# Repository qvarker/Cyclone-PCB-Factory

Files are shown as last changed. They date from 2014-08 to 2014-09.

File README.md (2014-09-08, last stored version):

Cyclone-PCB-Factory v0.9.7  
===================

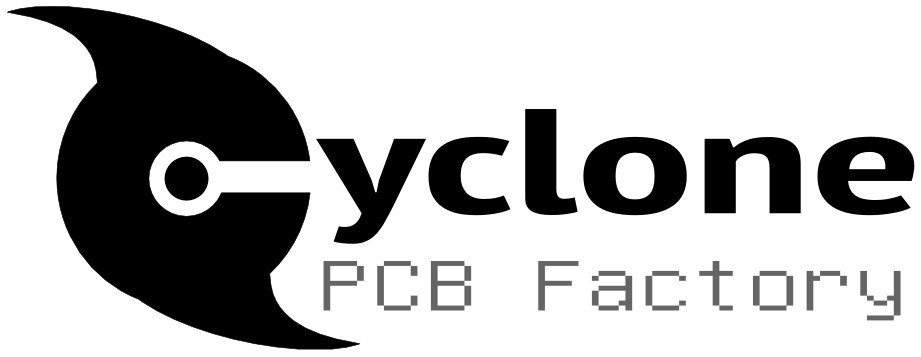
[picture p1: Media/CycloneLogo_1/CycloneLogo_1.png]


The first 3D-printable (Rep-Rap alike) CNC machine, intended for PCB manufacture.  

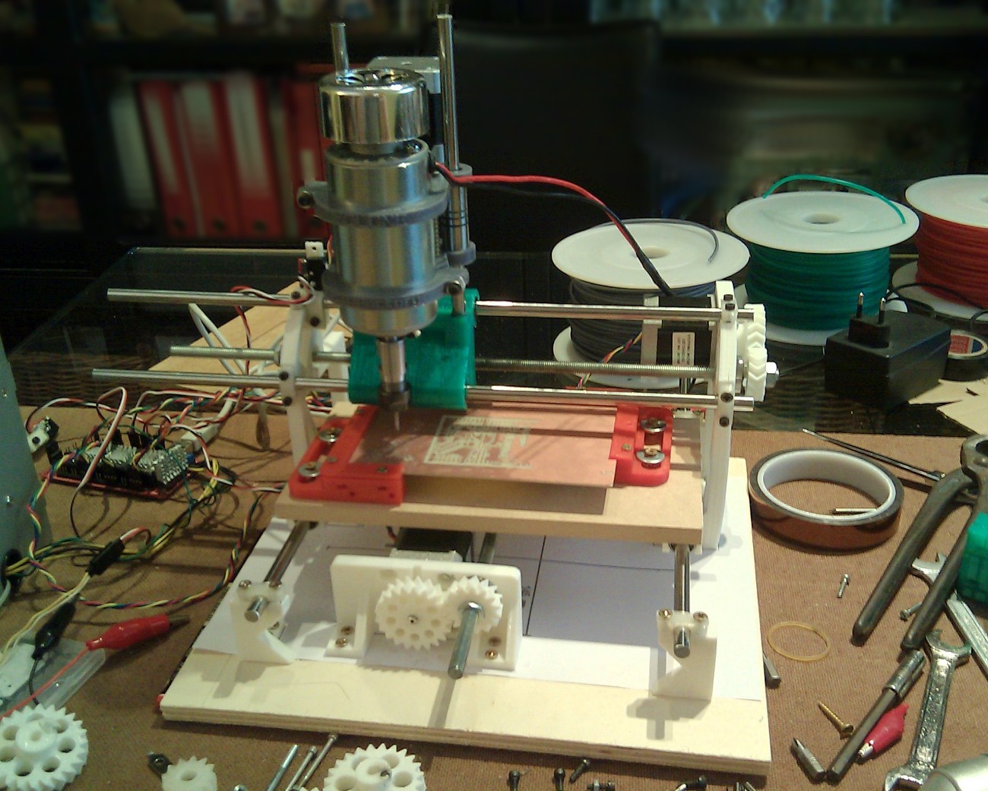
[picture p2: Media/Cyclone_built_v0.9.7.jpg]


Mail list / Forum  
--
If you are interested in this project, please consider joining our mail list:  
**<https://groups.google.com/forum/#!forum/cyclone-pcb-factory>**  
Any help is appreciated, particularly with software development :)  

Wiki entry on RepRap.org  
--
<http://reprap.org/wiki/Cyclone_PCB_Factory>  

*Must read: Progress and current status of the Cyclone proyect:*
<http://carlosgs.es/node/47>

Getting the source code  
--
Install git (http://git-scm.com/) onto your system. Then run a clone:

    git clone git://github.com/carlosgs/Cyclone-PCB-Factory.git

This will download the latest sources into a directory named 'openscad'. 

To pull the MCAD (<http://reprap.org/wiki/MCAD>) and Obiscad (<https://github.com/Obijuan/obiscad>) libraries, do the following:

    cd Cyclone-PCB-Factory
    git submodule update --init

Bill of materials  
--  
_Work in progress_  
Kobus' <https://docs.google.com/spreadsheet/ccc?key=0AjYcEd1WlkqCdERINEFvRk9mVTZvdXZFR0VHVjRWc2c#gid=0>  
Robsbots' <https://docs.google.com/spreadsheet/ccc?key=0AmiiQRLnjs9cdE12VDFmTHJ4N3JoTzcwbkJPb0ZLSWc#gid=0>  
Carlosgs' <https://docs.google.com/spreadsheet/ccc?key=0AsQp8IK25R4IdGk3LTdOWmpFR0Nrc0RhaVJaUC1CMUE>  

Tutorials  
--
_Work in progress_  
<http://reprap.org/wiki/Cyclone_PCB_Factory>  

Also take a look to these branches  
--  
<https://github.com/yOPERO/Cyclone-PCB-Factory>  
<https://github.com/glenchung/Cyclone-PCB-Factory>  
More: <https://github.com/carlosgs/Cyclone-PCB-Factory/graphs/contributors>  

To-Do list  
--  
- **Firmware:**  
 - Keep motors always on, in order to do homing only once each milling session  
- **Misc:**  
 - Create assembly instructions  

News  
--  
**Firmware**  
- No news, it is Marlin with support for G30 probing command  

Interesting links & Misc. ideas  
--
- **Open Source SMT Pick and Place Hardware and Software** <https://github.com/openpnp/openpnp> via **Marcos Villacampa** (@MarkVillacampa)  
- **Water-cooled spindle motors!** <http://www.goodluckbuy.com/electronics/motor-and-controller.html> via **Marcos Villacampa** (@MarkVillacampa)  
- **We could use a thermistor to measure the temperature of the spindle motor:** this way the software could "let it rest" when it gets too hot.  

Videos  
--  
- v0.9.7 [Cyclone PCB factory] The process (June 2013, v0.9.7)  <http://www.youtube.com/watch?v=fKW3fwy1h0k>
- v0.9.6 Y axis concept by Yopero <http://www.youtube.com/watch?v=XzcobonQP40>  
- v0.9.5 Probing a PCB <http://www.youtube.com/watch?v=m5zXL8k5T9E>  
- v0.9.5 Milling MDF <http://www.youtube.com/watch?v=2QpxjheEjEc> and <http://www.youtube.com/watch?v=zjav0hBtmYA>  
- v0.8 Drawing test: <http://www.youtube.com/watch?v=Y-HSdE89JOM>  
- v0.7.5 XY axis test: <http://www.youtube.com/watch?v=9umlq4oHG64>  
- v0.7.5 High speed XY test: <http://www.youtube.com/watch?v=H3uYCXryj60>  

License  
--
**Attribution - Share Alike - Creative Commons (<http://creativecommons.org/licenses/by-sa/3.0/>)**  

Authors  
--
_Check Hardware, Software and Firmware sections for details regarding authorship_  

Render (v0.9.7)  
--
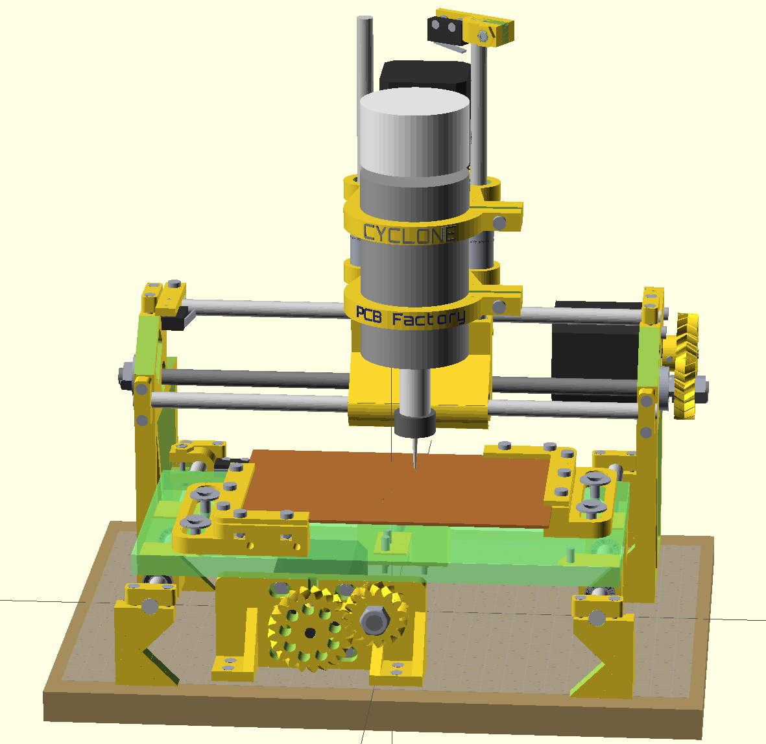
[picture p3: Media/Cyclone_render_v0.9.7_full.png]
  
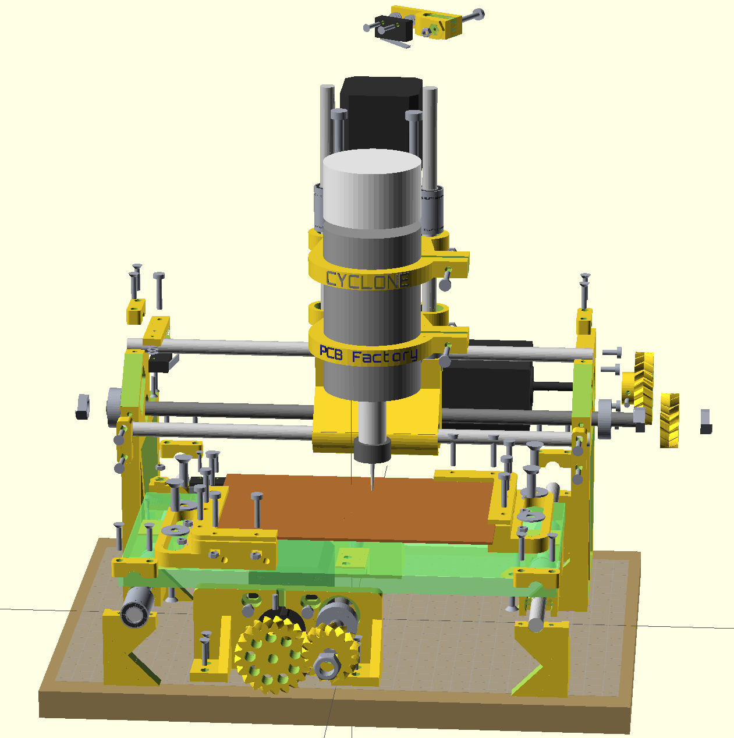
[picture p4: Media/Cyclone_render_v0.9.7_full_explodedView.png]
  
**Thanks a lot to Glen Chung for the fully assembled renders**  

Disclaimer  
--
This hardware/software is provided "as is", and you use the hardware/software at your own risk. Under nocircumstances shall any author be liable for direct, indirect, special, incidental, or consequential damages resulting from the use, misuse, or inability to use this hardware/software, even if the authors have been advised of the possibility of such damages.

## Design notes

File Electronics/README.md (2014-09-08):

Electronics for Cyclone-PCB-Factory  
===================

Electronic boards (and firmwares) for controlling Cyclone PCB Factory and similar machines  

* [Spindle controller by Samuel Kranz](https://github.com/secures92/SpindleControlStick) and [Controller board by Robert Last](https://github.com/robsbots/Cyclone_Pcb):

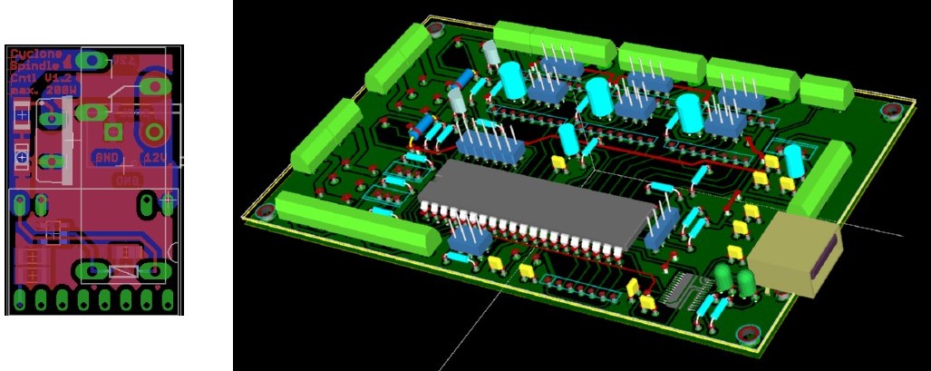
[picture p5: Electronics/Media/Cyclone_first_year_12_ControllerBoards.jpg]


* [GRBL-based controller board by Samuel Kranz](https://github.com/secures92/CyclneGRBLCtrl):

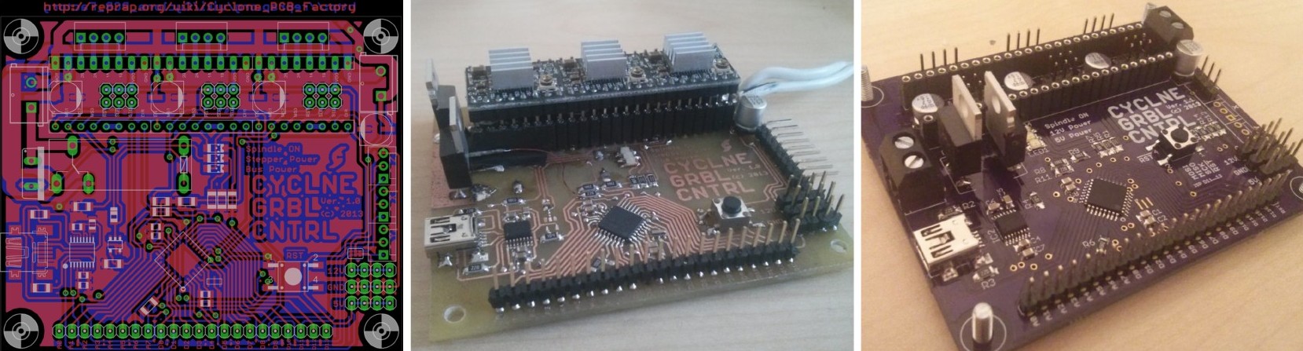
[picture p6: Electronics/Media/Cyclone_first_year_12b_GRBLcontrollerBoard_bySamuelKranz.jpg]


* [CNC Shield by Protoneer](http://blog.protoneer.co.nz/arduino-cnc-shield/) and [CNC Shield box by yOPERO](../Hardware/yOPERO/CNC_shieldBox):

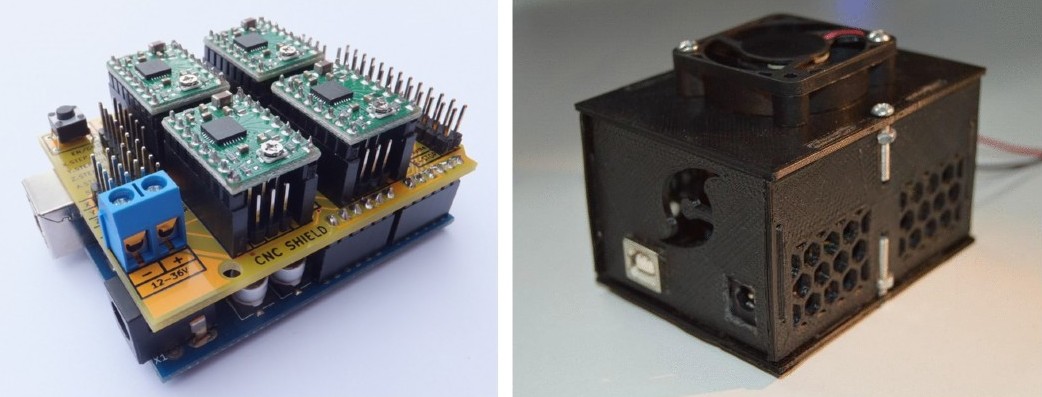
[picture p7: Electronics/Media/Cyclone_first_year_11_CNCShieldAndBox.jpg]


Disclaimer  
--
This hardware/software is provided "as is", and you use the hardware/software at your own risk. Under nocircumstances shall any author be liable for direct, indirect, special, incidental, or consequential damages resulting from the use, misuse, or inability to use this hardware/software, even if the authors have been advised of the possibility of such damages.

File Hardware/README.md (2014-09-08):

Hardware for Cyclone-PCB-Factory  
===================

To-Do list  
--  
There are plenty of work fronts open, as many task are pending:

* Tougher parts (great ongoing work!):
 * Stronger holders for the linear bearings (vibration makes them slide away)
 * Reinforce screw holders
* Attachment for a vacuum cleaner
* Better scalability (particularly for the Y axis)
* Better spindle motor design:
 * Brushless motor for the spindle
 * Spindle speed control
* Integrated endstop holders

News  
-- 
* Check out [yOPERO's variant of Cyclone](yOPERO/):

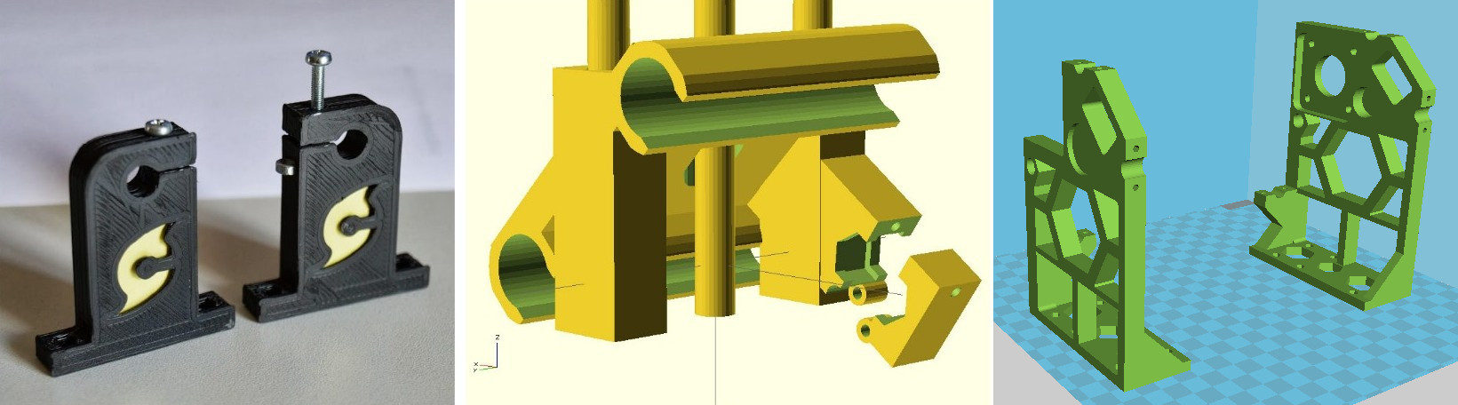
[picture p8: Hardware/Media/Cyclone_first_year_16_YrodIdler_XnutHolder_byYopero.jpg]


* Check out these [sturdy frames by Jiří Pilný](https://groups.google.com/forum/#!msg/cyclone-pcb-factory/uVLyKMvz4hA/HmpsZP1CiLUJ):

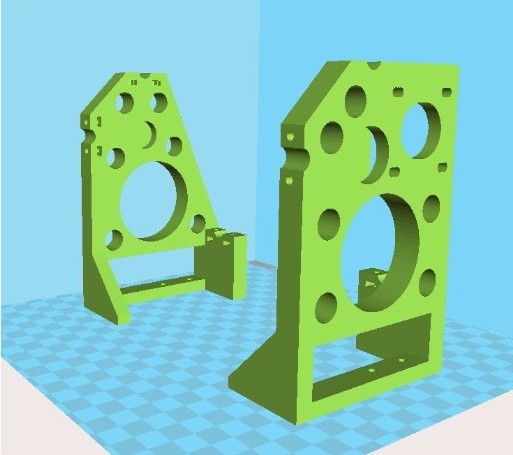
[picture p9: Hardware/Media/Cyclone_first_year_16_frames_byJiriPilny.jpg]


* Check out [Martin's variant of Cyclone](http://www.thingiverse.com/thing:230233):

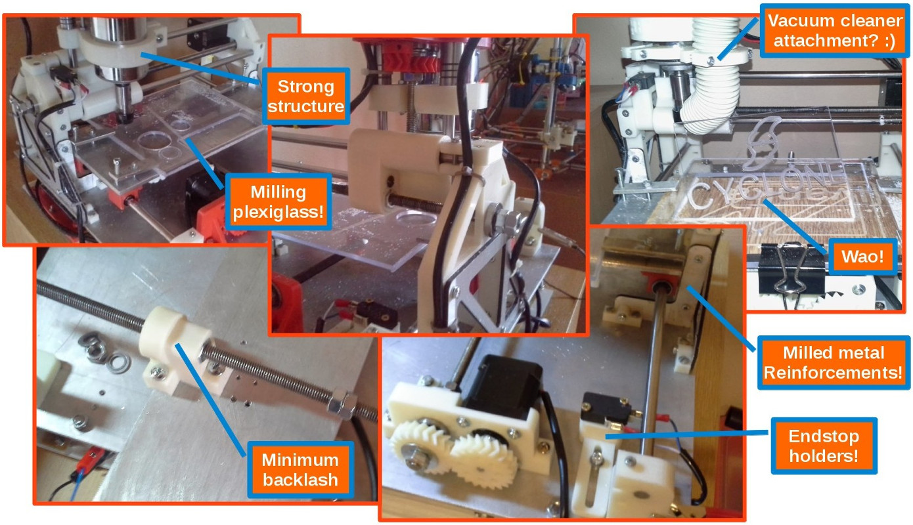
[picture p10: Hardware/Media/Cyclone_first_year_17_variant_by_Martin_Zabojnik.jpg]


Render (v0.9.7)  
--
  
  
**Thanks a lot to Glen Chung for the fully assembled renders**  

Notes  
--  
- Using a thick wood piece as the main base.  
- As shown in one of the pictures, a cheap dremel-like drill has nice bearings and is a good option as the main tool. **Finally it will be using a proper spindle** (check the BOM for the reference).  
- Desired working range of >=100mm for the X axis and >=160mm for the Y axis.  
- Parts are designed to be printable with the small volume of a Printrbot Jr  
- Bed leveling is done with probing and an appropriate software.  

License  
--
License: **Attribution - Share Alike - Creative Commons (<http://creativecommons.org/licenses/by-sa/3.0/>)**  

Authors (Hardware):  
--
- **Carlos García Saura (Carlosgs <http://carlosgs.es>)** (original design)  
- **Daniel Garrido (yOPERO <https://github.com/yOPERO> & <http://yopero-tech.blogspot.com.es/>)** (hardware improvements)  
- **Harry Binnema** (hardware improvements)
- **Glen Chung (<https://github.com/glenchung>)** (Full assembly in OpenScad)
- **Jiří Pilný** (hardware improvements)
- **Martin Zabojnik** (hardware improvements)

Special thanks  
--  
- Z axis concepts by **Quim Borras** and the spindle motor holder by **Misan** were really useful!! Also, **Diego Viejo**'s machine was of great inspiration for the Z axis (<https://plus.google.com/u/0/photos/113930344830086538817/albums/5868944432651911713?authkey=CLDJgdehlN773gE>) **Thank you all!!**  
- This design woudn't have been possible without the encouragement of the **Panda CNC community** (<https://plus.google.com/u/0/communities/102402711800402614517>)  
- Also, thanks to **Juan González-Gómez (Obijuan <http://iearobotics.com>)** for naming the machine Cyclone :)  

Derived from / we have used / inspirational  
--
- "Linear actuator concept for CNC machines" by **Carlosgs** (<http://www.thingiverse.com/thing:45103>)  
- "Obiscad library" by **Obijuan** (<https://github.com/Obijuan/obiscad>)  
- "Minimal footprint friction-fit LM8UU holder" by **thantik** (<http://www.thingiverse.com/thing:23041>)  
- "Spindle mount for ShapeOko" by **Misan** (<http://www.thingiverse.com/thing:26740>)  
- "Carro Z para Cyclone CNC mill intended for PCB" by **Quim** (<http://www.thingiverse.com/thing:80718>)  
- "Write.scad (and DXF fonts)" by **HarlanDMii** (<http://www.thingiverse.com/thing:16193>)  
- "PCB Machining Vise" by **Forgetful_Guy** (<http://www.thingiverse.com/thing:63578>)  

Credit for the ideas used  
--  
The origin of Cyclone took place while I was inside the **Panda CNC** community (<https://plus.google.com/u/0/communities/102402711800402614517>). This is from December 2012 to mid-February 2013.  
Here is the credit for the ideas that were used:  

* _Let's design a 3D-printable CNC for PCB milling, it will be named Panda:_ **Guillermo Welch** (mid-December, via Google Talk)  
* _X carriage rod distribution:_ **César Augusto Fernández Cano** claims Cyclone's X axis is a derivate of his concept: <https://plus.google.com/u/0/111421387442355054591/posts/QrfYtEuZBaj>  
* _100x160mm workspace:_ **David Martin** <https://dl.dropboxusercontent.com/u/16122275/PandaCNC_credit/workplace_size.png>  
* _Using gears to drive the X-Y axes:_ **Guillermo Welch** <https://plus.google.com/u/0/101232926728463427403/posts/QjZGNcWcgGg>  
* _Regarding the woodbase:_ **Guillermo Welch** always contemplated the possibility of attaching the machine (optionally) to a woodbase. I decided to use the base as a main structural part instead. See <https://dl.dropboxusercontent.com/u/16122275/PandaCNC_credit/woodbase.png> (screenshot from <https://plus.google.com/u/0/113437723819360223498/posts/8LDCSSVWqCS>)  
* _List of CNC endmill types:_ **David Martin** <https://dl.dropboxusercontent.com/u/16122275/PandaCNC_credit/cnc_endmill_types.png>  

Please note I have taken screenshots of the post that are on the closed G+ Panda community (<https://plus.google.com/u/0/communities/116318709564872967169>). You can register and see by yourself.  

**All other development present on Cyclone has nothing to do with Panda and is not related to the Panda project.**  

Disclaimer  
--
This hardware/software is provided "as is", and you use the hardware/software at your own risk. Under nocircumstances shall any author be liable for direct, indirect, special, incidental, or consequential damages resulting from the use, misuse, or inability to use this hardware/software, even if the authors have been advised of the possibility of such damages.

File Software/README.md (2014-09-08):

Software for Cyclone-PCB-Factory  
===================

The original python scripts were only a proof of concept: the lack of GUI was a big drawback.  

Some alternatives were suggested, and two of them have been made by developers inside the group. Kobus Du Toit and Patrick Knöbel have worked on two different alternatives that simplify the task of Z probing by making it more visual and intuitive for the end users:  

* [Kobus's GUI](https://www.dropbox.com/sh/k7p896n0upv29u1/1T_lcIZDnH/prototypeGui2) ([forum](https://groups.google.com/forum/#!msg/cyclone-pcb-factory/S3m1baPzwRk/DtyngGGJmBoJ)) and [Patrick Knöbel's gcode postprocessor](https://github.com/pknoe3lh/cncgcodecontroller/releases) ([forum](https://groups.google.com/forum/#!msg/cyclone-pcb-factory/ToTGIpXWUmA/gyQMDqDOXfUJ)):

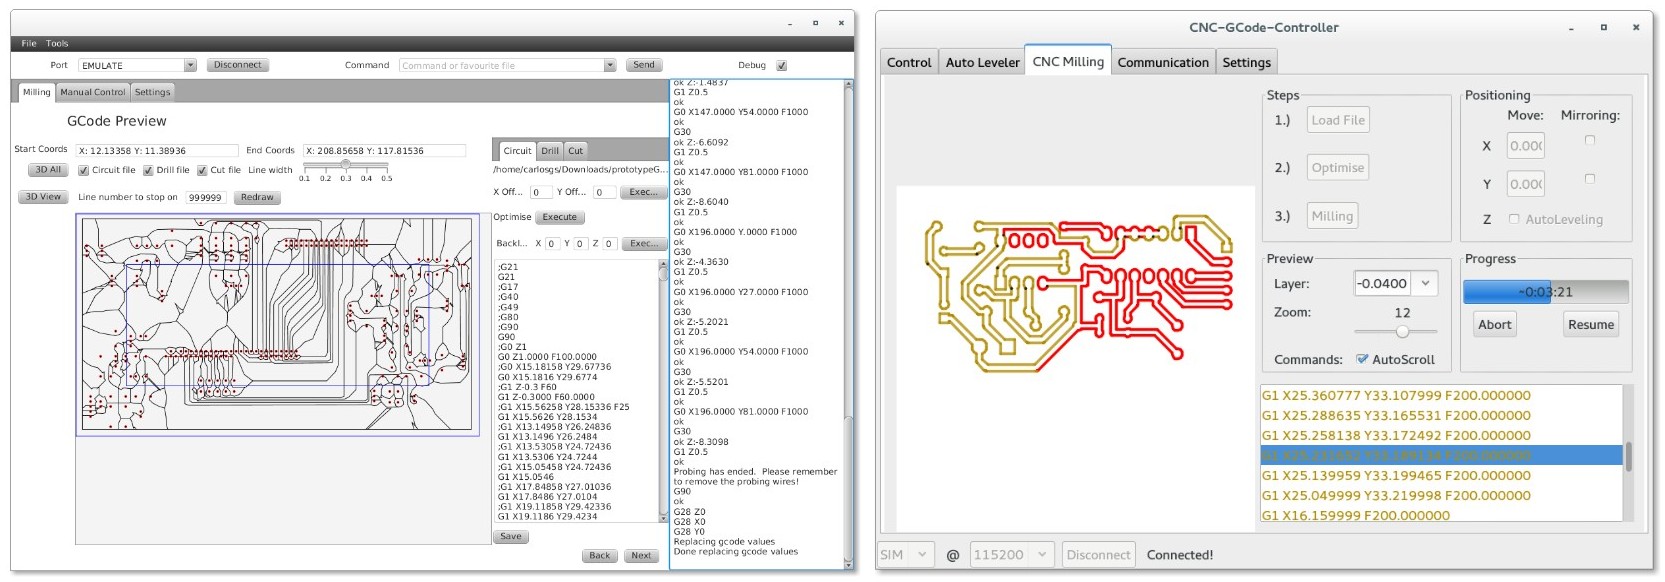
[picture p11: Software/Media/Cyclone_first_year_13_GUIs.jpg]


* [Python scripts by Carlosgs](PythonScripts/):

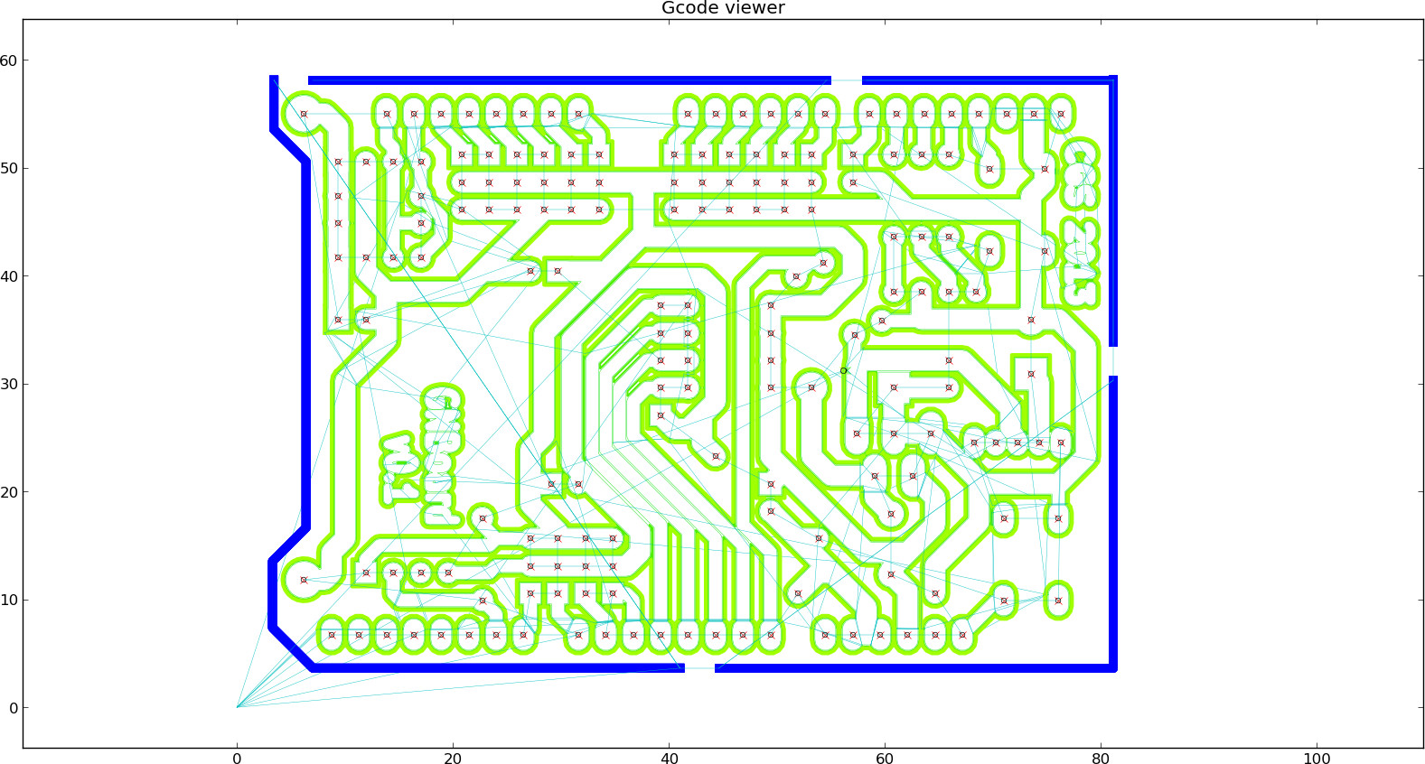
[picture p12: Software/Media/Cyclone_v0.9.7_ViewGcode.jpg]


Disclaimer  
--
This hardware/software is provided "as is", and you use the hardware/software at your own risk. Under nocircumstances shall any author be liable for direct, indirect, special, incidental, or consequential damages resulting from the use, misuse, or inability to use this hardware/software, even if the authors have been advised of the possibility of such damages.

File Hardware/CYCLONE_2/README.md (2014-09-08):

Hardware for Cyclone-PCB-Factory  
===================

Version 2.0a  
--  
Adressing all the issues from the original design, and implementing improvements by yOPERO, Martin Zabojnik and others.

* More robust design with tougher parts:
 * Better holders for the linear bearings (vibration made them slide away)
 * Reinforced nut/screw holders
* Improved [gears](INHERITED) with smoother edges
* Attachment for a vacuum cleaner
* Better scalability (parameterized design)
* Using a [Dremel 200](http://www.dremel.com/en-us/tools/Pages/ToolDetail.aspx?pid=200+Series) as the spindle motor
* Integrated endstop holders

Work in progress. Pending tasks:  
--  
* Improve vacuum cleaner attachment (make it detachable)
* Finish protective covers for the gears
* Endstop integration for Z
* Better plastic-saving holes for the X frames
* Improve the nut holder in the X carriage (with the same spring mechanism as in Y)
* Re-design the [Z carriage](INHERITED) after testing performance

  

The new design tries to be more parameterized:

  

Disclaimer  
--
This hardware/software is provided "as is", and you use the hardware/software at your own risk. Under nocircumstances shall any author be liable for direct, indirect, special, incidental, or consequential damages resulting from the use, misuse, or inability to use this hardware/software, even if the authors have been advised of the possibility of such damages.

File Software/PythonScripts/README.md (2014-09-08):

Software for Cyclone-PCB-Factory  
===================

**To-Do list**  
--  
- Create simple program to provide Z probing support for any Gcode
- Graphical User Interface (development in progress in the mail-list)
- Note: The timeout for commands need to be increased.

News  
--
- _TO-DO update this list_
- First Z probing results are promising, read: <https://plus.google.com/u/0/113437723819360223498/posts/9VCHqqnirj6> and <https://plus.google.com/u/0/113437723819360223498/posts/89W2cv1fgQW>  
- Added the python probing script (v0.1) and Octave/Matlab visualizer  

Software: previous existing work  
--  
Here is a compilation of links that have inspired the software controller (specifically the Z probing technique):  

- <http://www.re-innovation.co.uk/web12/index.php/en/blog-75/181-making-pcbs-with-a-cnc-machine>  
- <http://phk.freebsd.dk/CncPcb/>  
- <http://wiki.linuxcnc.org/cgi-bin/wiki.pl?Touch_Probe>  
- <http://things.onshoulders.org/software/PcbSubtraction.php>  
- <http://www.cnczone.com/forums/pcb_milling/82628-cheap_simple_height-probing-5.html>  
- <http://drillcity.stores.yahoo.net/>  
- <http://www.drewtronics.net/>  

- **Examples of the PCB probing method**  
 - onshouldersTv: Open Source Circuit Boards at Home <http://www.youtube.com/watch?v=L-5SRtwx3kY>  
 - PCB routing using the Probe method <http://www.youtube.com/watch?v=fwgT9sCL8fs>  
- <http://pcbgcode.org/>  
- <http://sourceforge.net/apps/mediawiki/pcb2gcode/index.php?title=Main_Page>  
- Very interesting toguether with cam.py: <http://code.google.com/p/pygerber2gcode/>  
- <http://replicat.org/generators>  
- For arranging panels: <http://ruggedcircuits.com/gerbmerge/>  

License  
--
**Attribution - Share Alike - Creative Commons (<http://creativecommons.org/licenses/by-sa/3.0/>)**  

Authors (Software)  
--
- **Carlos García Saura (Carlosgs <http://carlosgs.es>)** (original python scripts)  
- _GUI work in progress by various members of the mail-list_  

Disclaimer  
--
This hardware/software is provided "as is", and you use the hardware/software at your own risk. Under nocircumstances shall any author be liable for direct, indirect, special, incidental, or consequential damages resulting from the use, misuse, or inability to use this hardware/software, even if the authors have been advised of the possibility of such damages.

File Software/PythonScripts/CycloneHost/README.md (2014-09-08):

Cyclone Host  
===================

_**Cyclone host v1.0**_  
 
DESCRIPTION:  
--
Controller for the Cyclone PCB Factory, "a 3D printable CNC machine for PCB manufacture" (http://www.thingiverse.com/thing:49484)  
This software has been tested with a Sanguinololu board running a modified Marlin firmware that supports the G30 probing G-code.  
 
AUTHOR:  
--
Carlosgs (http://carlosgs.es)

LICENSE:  
--
Attribution - Share Alike - Creative Commons (http://creativecommons.org/licenses/by-sa/3.0/)  
 
DISCLAIMER:  
--
This software is provided “as is," and you use the software at your own risk. Under no circumstances shall Carlosgs be liable for direct, indirect, special, incidental, or consequential damages resulting from the use, misuse, or inability to use this software, even if Carlosgs has been advised of the possibility of such damages.  

CREDIT:  
--
This script was created using as a base:  
"Upload GCode to SpereBot" by Tgfuellner http://www.thingiverse.com/thing:9941 (CC-BY-SA)  
Please refer to http://carlosgs.es for more information on this probing method  
 
REQUISITE:  
--
http://pyserial.sourceforge.net  
Installation on Ubuntu: sudo aptitude install python-serial

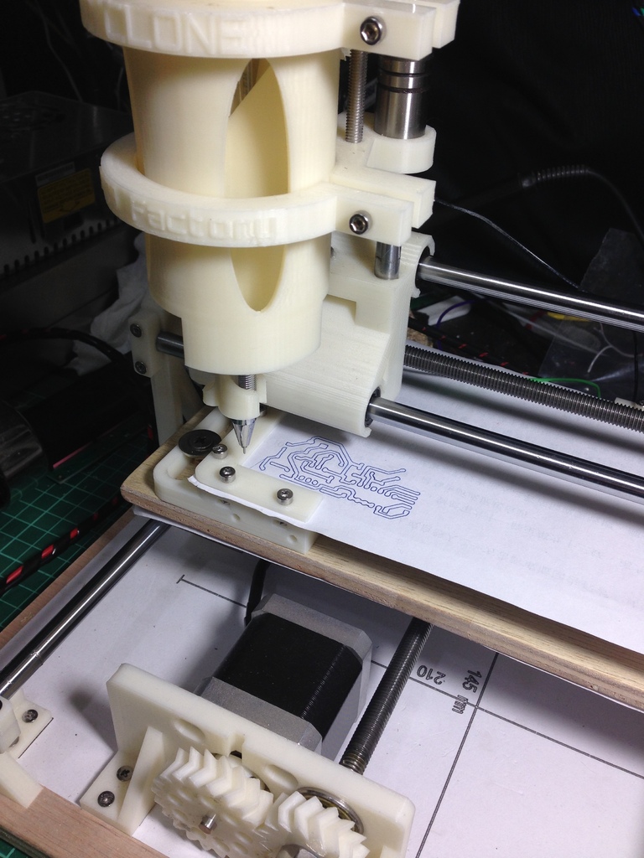
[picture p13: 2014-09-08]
Hardware/Spindle_Pen/img/IMG_9989_display_large.jpg

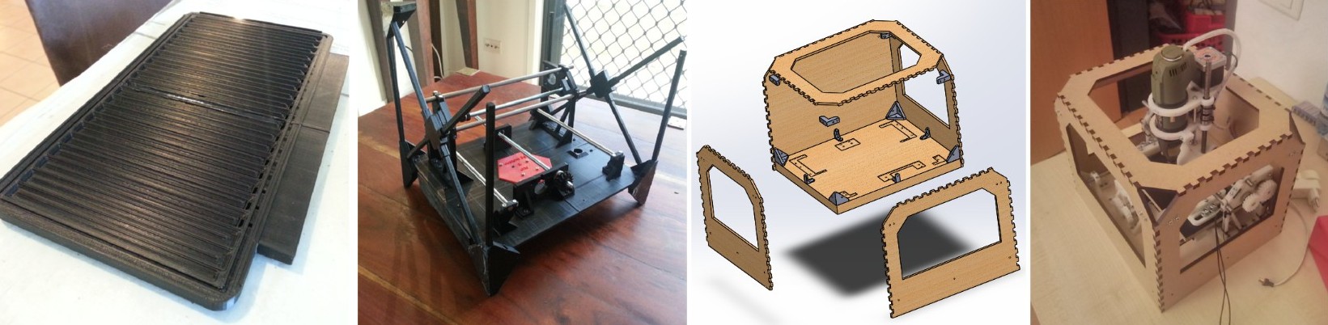
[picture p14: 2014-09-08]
Hardware/Media/Cyclone_first_year_15_VacuumTable_box_byKobusDuToit_and_container_bySamuelKranz.jpg

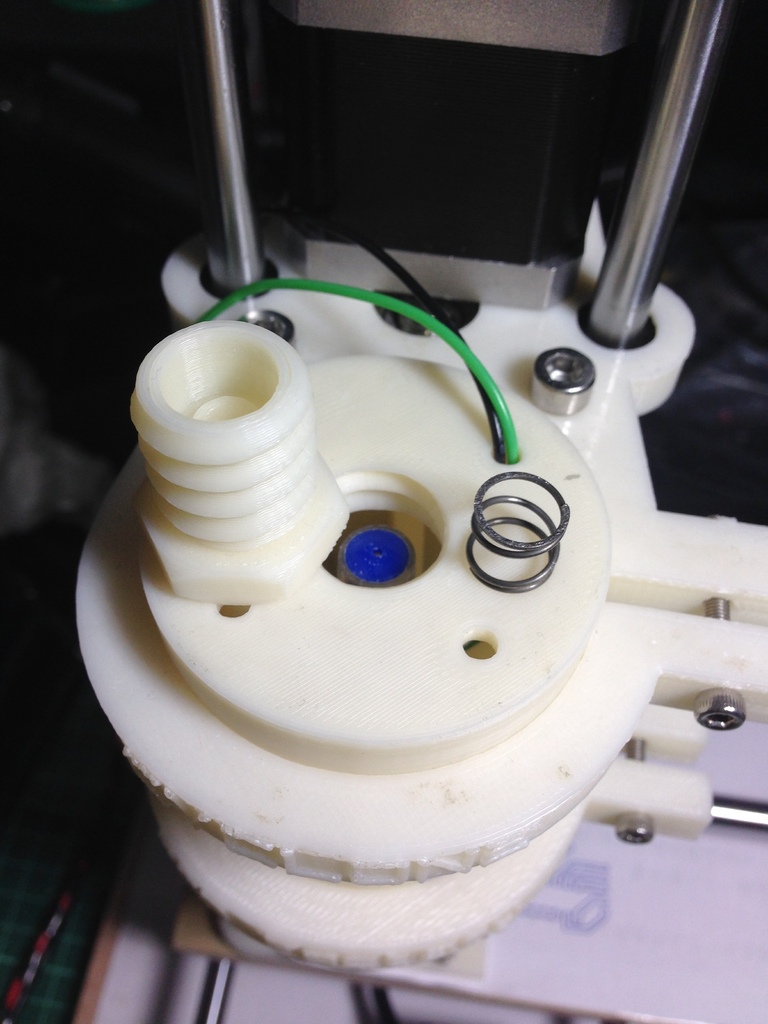
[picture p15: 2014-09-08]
Hardware/Spindle_Pen/img/IMG_9990_display_large.jpg

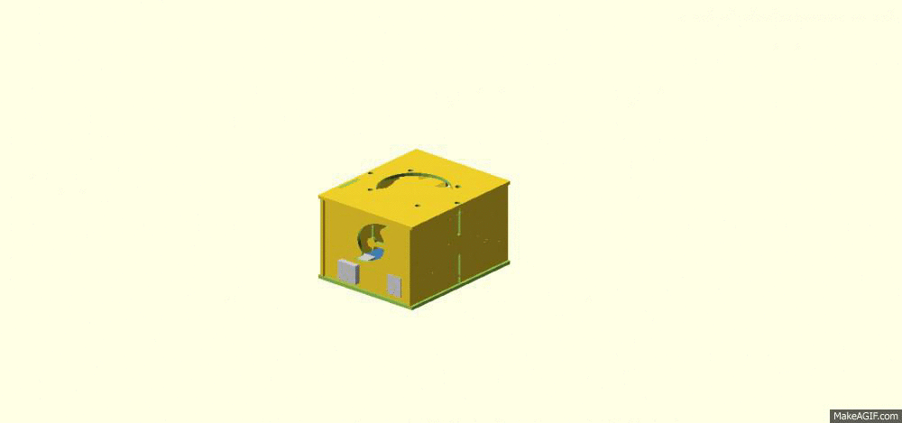
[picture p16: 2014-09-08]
Hardware/yOPERO/CNC_shieldBox/Pictures/template.gif

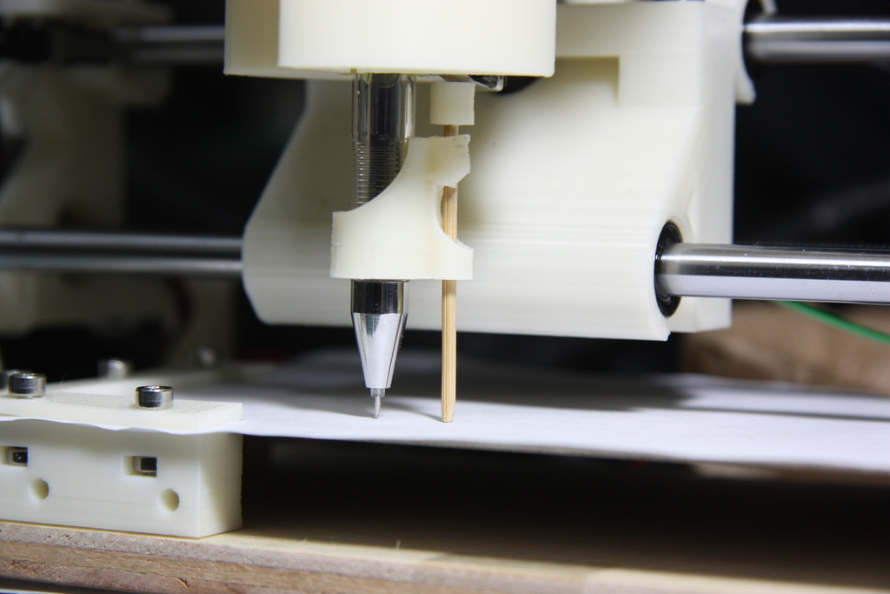
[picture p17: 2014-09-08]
Hardware/Spindle_Pen/img/IMG_2629_display_large.jpg

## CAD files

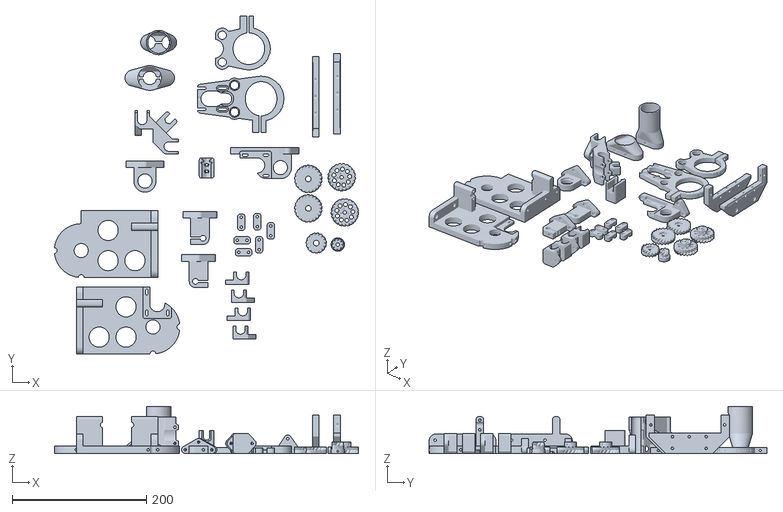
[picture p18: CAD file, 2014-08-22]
Hardware/CYCLONE_2/output/STL_plates/Cyclone_fullPlate_8aug2014.stl
452.3 x 502.5 x 70.0

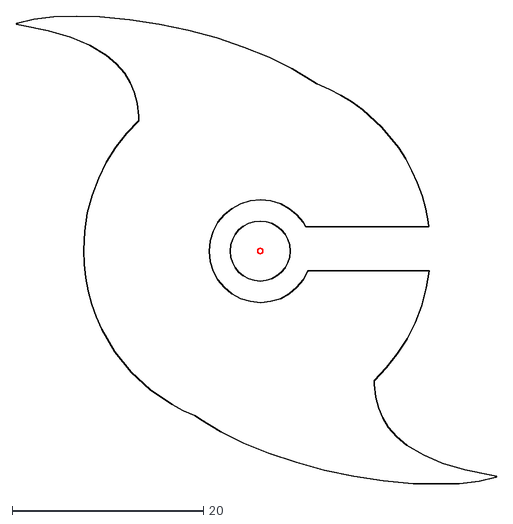
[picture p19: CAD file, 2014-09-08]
Hardware/CYCLONE_2/dxf/CycloneLogo.dxf
50.2 x 48.8

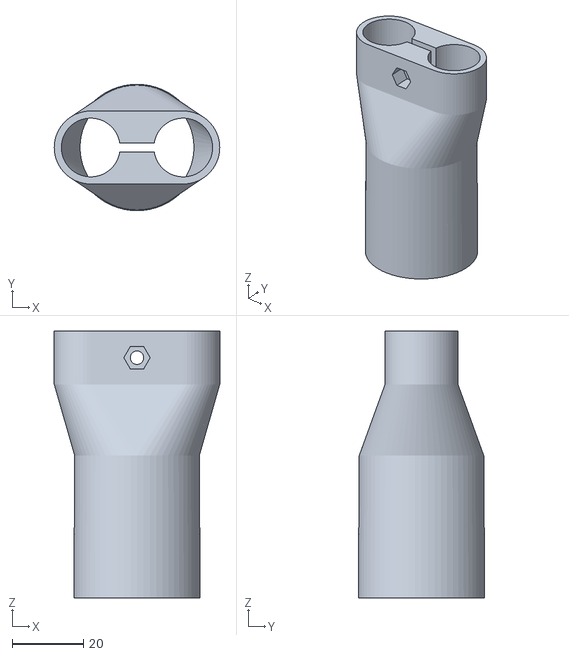
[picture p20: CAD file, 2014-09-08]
Hardware/CYCLONE_2/INHERITED/stl/vacuum_cleaner_attachment.stl
46.5 x 35.5 x 75.0

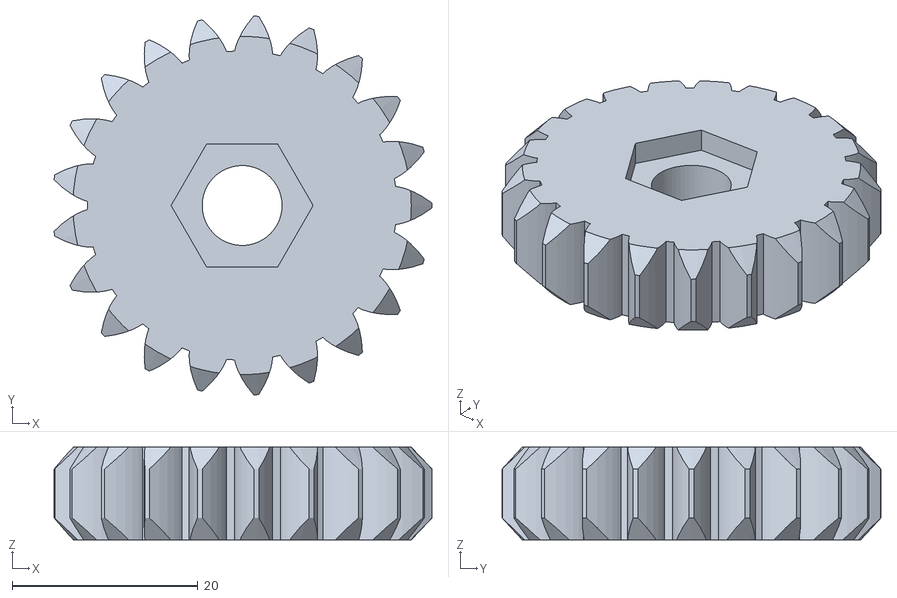
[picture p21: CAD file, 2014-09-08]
Hardware/CYCLONE_2/INHERITED/XYgears/XYrod_gear.stl
40.7 x 40.8 x 10.0

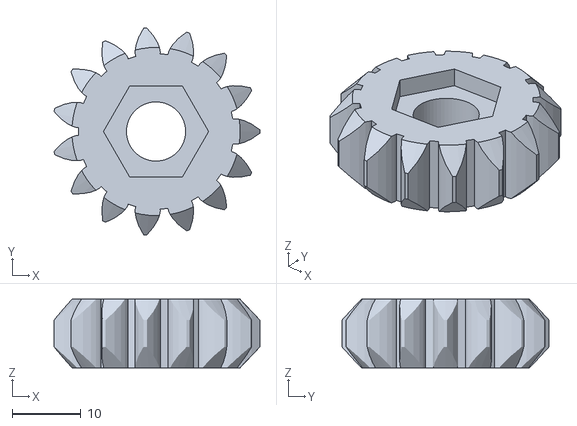
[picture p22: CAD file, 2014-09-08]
Hardware/CYCLONE_2/INHERITED/Zgears/Zrod_gear.stl
29.9 x 30.1 x 10.0

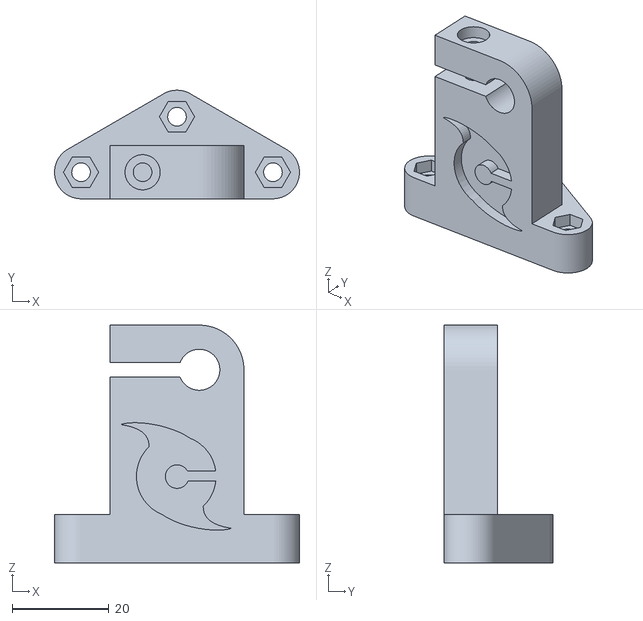
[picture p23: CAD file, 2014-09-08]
Hardware/CYCLONE_2/output/Cyclone_YfrontLeft_RodIdler.stl
50.8 x 22.5 x 49.2

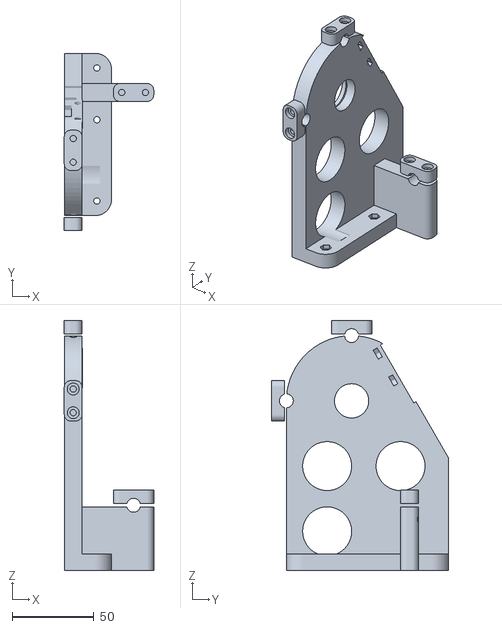
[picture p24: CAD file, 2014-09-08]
Hardware/CYCLONE_2/output/ShorterVersion/Cyclone_XrightFrame.stl
54.9 x 108.8 x 153.2

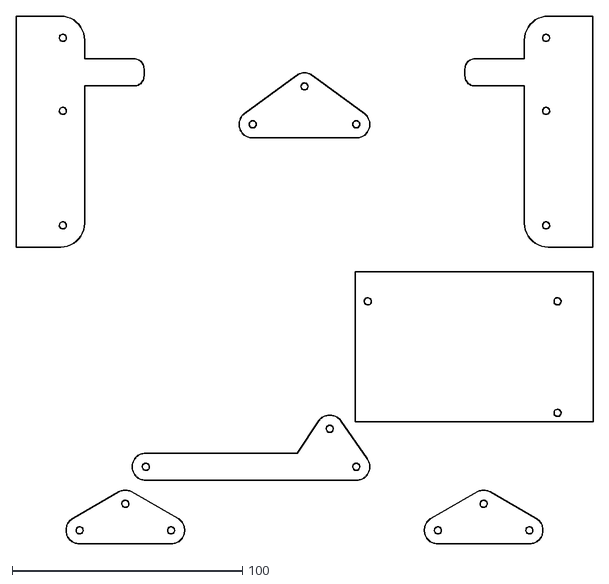
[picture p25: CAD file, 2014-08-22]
Hardware/CYCLONE_2/output/templates/Cyclone_base_template.dxf
250.8 x 229.3

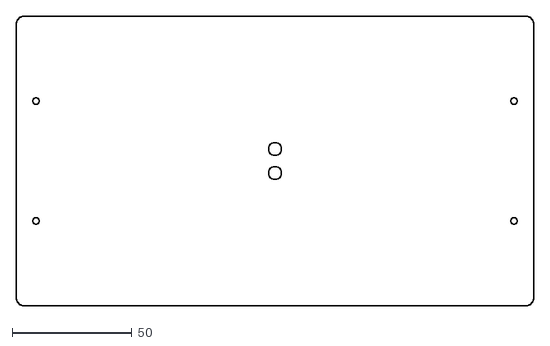
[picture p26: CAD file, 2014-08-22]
Hardware/CYCLONE_2/output/templates/laserCut/Cyclone_workbed_3mm.dxf
216.0 x 121.0

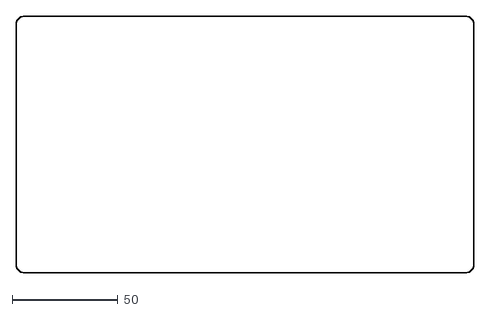
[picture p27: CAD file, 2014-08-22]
Hardware/CYCLONE_2/output/templates/laserCut/separate/Cyclone_workbed_outline.dxf
216.0 x 121.0

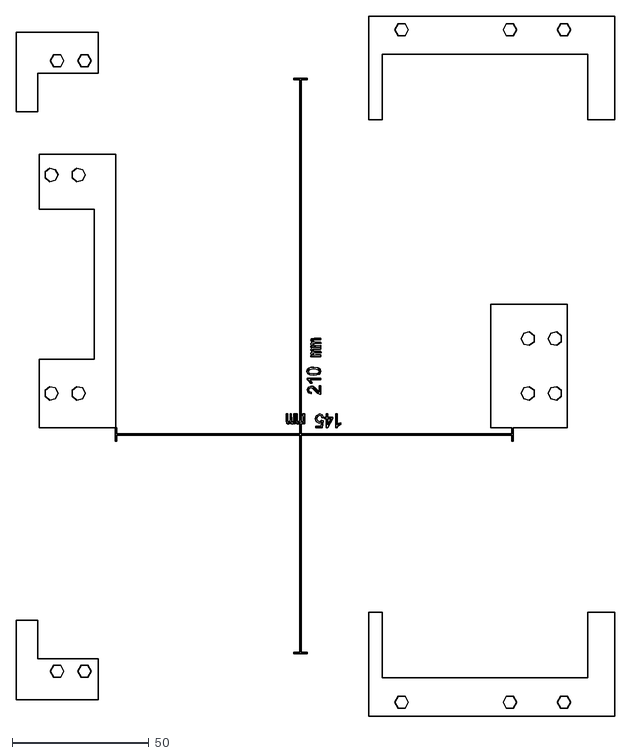
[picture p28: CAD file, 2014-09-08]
Hardware/Cyclone_Template/output/template.dxf
219.0 x 256.0

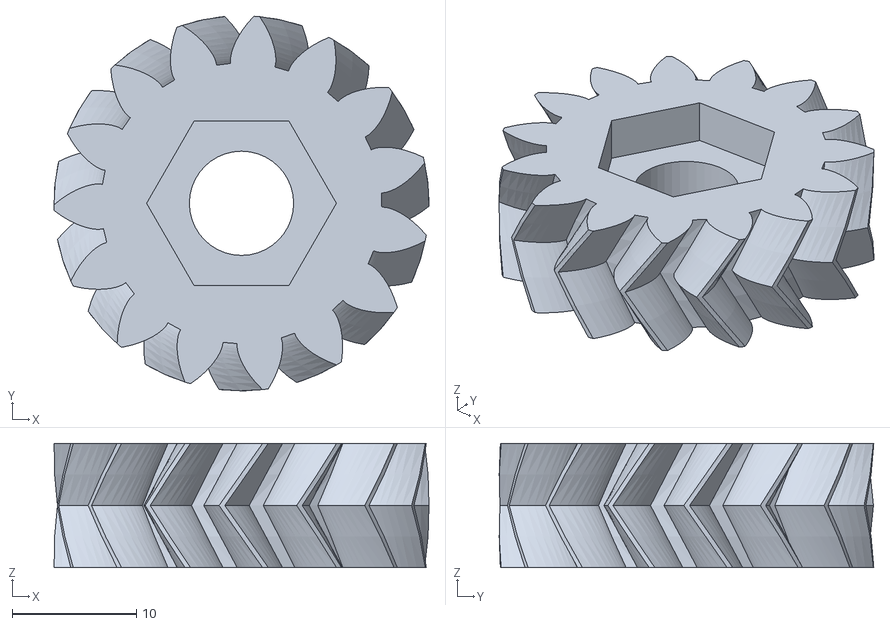
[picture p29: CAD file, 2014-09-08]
Hardware/Gears/stl/rod_gear_15.stl
30.2 x 30.2 x 10.0

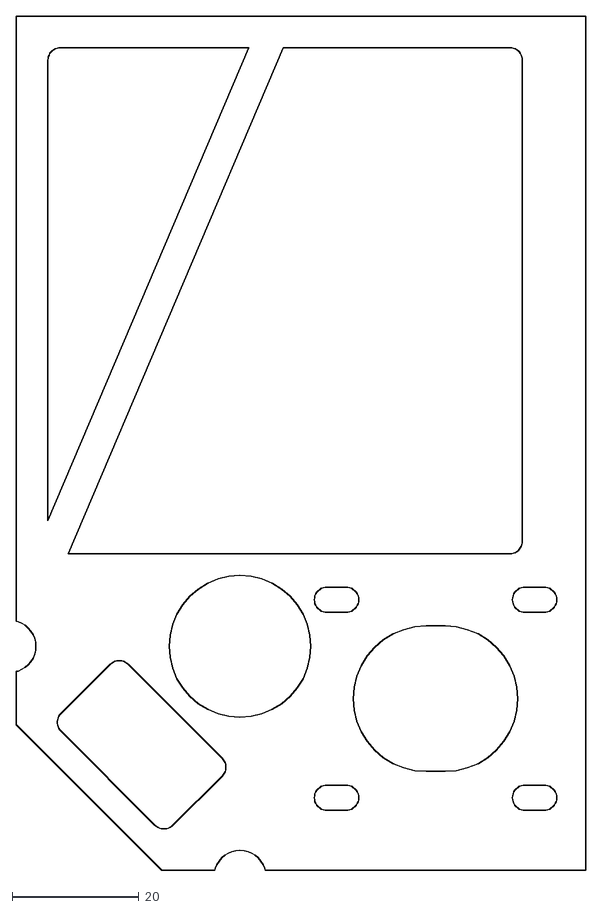
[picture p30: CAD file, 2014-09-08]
Hardware/main_frame/Flat_DXFs/frame.dxf
90.0 x 135.0

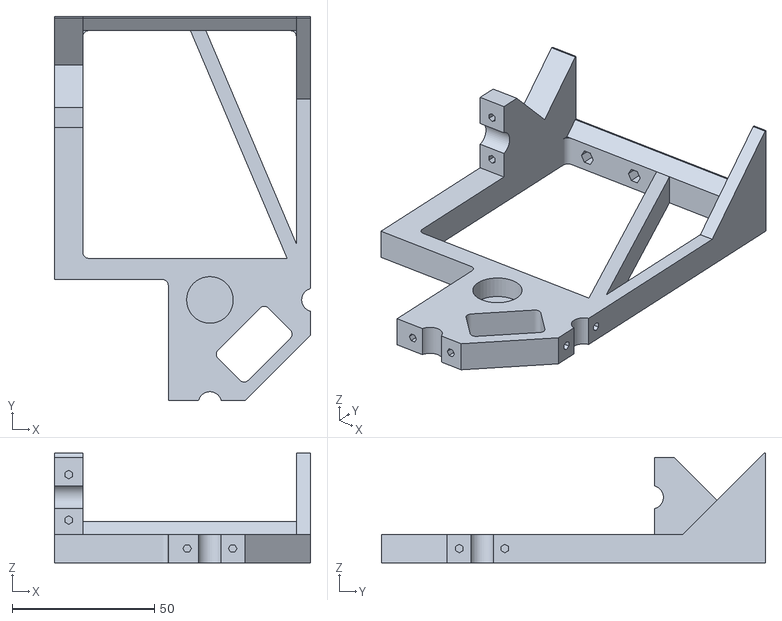
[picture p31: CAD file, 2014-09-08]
Hardware/main_frame/stl/frame_nomotor.stl
90.0 x 135.0 x 38.5

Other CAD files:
Hardware/CYCLONE_2/freecad/Cyclone_Y_leftHolder.fcstd
Hardware/smooth_rod_fix/stl/smooth_rod_fix.stl
Hardware/Vacuum_cleaner_attachment/prev/corrugated/vacuum_cleaner_attachment.stl
Hardware/Vacuum_cleaner_attachment/prev/vacuum_cleaner_attachment_2_3.stl
Hardware/Spindle_Pen/SpindlePen.scad
Hardware/Gears/motor_gear.scad
Hardware/XZ_axis/motor_gear.scad
Hardware/Y_axis/motor_stand.scad
Hardware/CYCLONE_2/Cyclone.scad
Hardware/CYCLONE_2/Cyclone_X_carriage.scad
Hardware/CYCLONE_2/Cyclone_X_frames.scad
Hardware/CYCLONE_2/Cyclone_Y_carriage.scad
Hardware/CYCLONE_2/Cyclone_Y_frames.scad
Hardware/CYCLONE_2/Cyclone_Z_carriage.scad
Hardware/CYCLONE_2/INHERITED/Cyclone_Zcarriage.scad
Hardware/CYCLONE_2/INHERITED/XYgears/XYmotor_gear.scad
Hardware/CYCLONE_2/INHERITED/XYgears/XYmotor_gear.stl
Hardware/CYCLONE_2/INHERITED/XYgears/XYrod_gear.scad
Hardware/CYCLONE_2/INHERITED/Zgears/Zmotor_gear.scad
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

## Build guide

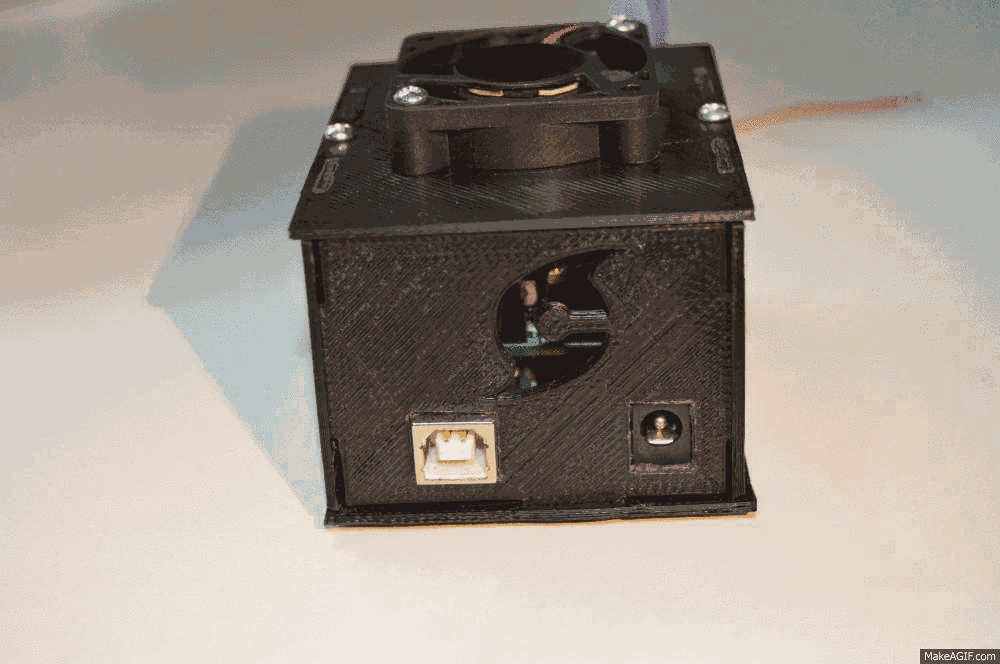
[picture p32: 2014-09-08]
Hardware/yOPERO/CNC_shieldBox/Pictures/printedSmall.gif

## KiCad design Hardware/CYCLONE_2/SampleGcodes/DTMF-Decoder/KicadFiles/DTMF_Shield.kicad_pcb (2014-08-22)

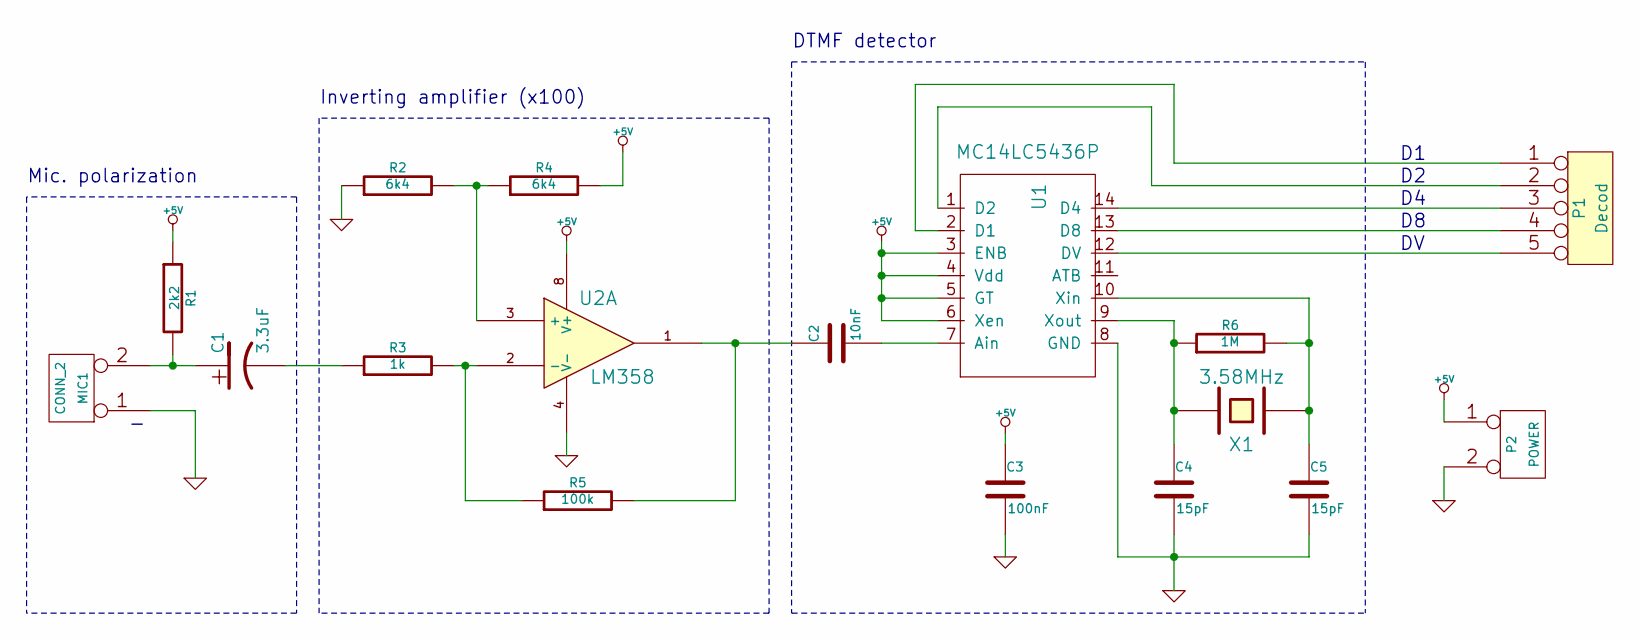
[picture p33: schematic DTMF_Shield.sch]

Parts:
C1: 3.3uF
C2: 10nF
C3: 100nF
C4, C5: 15pF
MIC1: CONN_2
P1: Decod
P2: POWER
R1: 2k2
R2, R4: 6k4
R3: 1k
R5: 100k
R6: 1M
U1: MC14LC5436P
U2: LM358
X1: 3.58MHz

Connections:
+5V: C3.1, P2.1, R1.1, R4.2, U1.3 (ENB), U1.4 (Vdd), U1.5 (GT), U1.6 (Xen), U2.8 (V+)
GND: C3.2, C4.2, C5.2, MIC1.1, P2.2 (PM), R2.1, U1.8 (GND), U2.4 (V-)
unnamed: C5.1, R6.2, U1.10 (Xin), X1.1
unnamed: C2.1, R5.2, U2.1
unnamed: R3.2, R5.1, U2.2 (-)
unnamed: C4.1, R6.1, U1.9 (Xout), X1.2
unnamed: C2.2, U1.7 (Ain)
unnamed: P1.4, U1.13 (D8)
unnamed: P1.1, U1.2 (D1)
unnamed: P1.2, U1.1 (D2)
unnamed: P1.3, U1.14 (D4)
unnamed: P1.5, U1.12 (DV)
unnamed: R2.2, R4.1, U2.3 (+)
unnamed: C1.1, MIC1.2 (PM), R1.2
unnamed: C1.2, R3.1

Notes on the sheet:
Inverting amplifier (x100)
Mic. polarization
DTMF detector

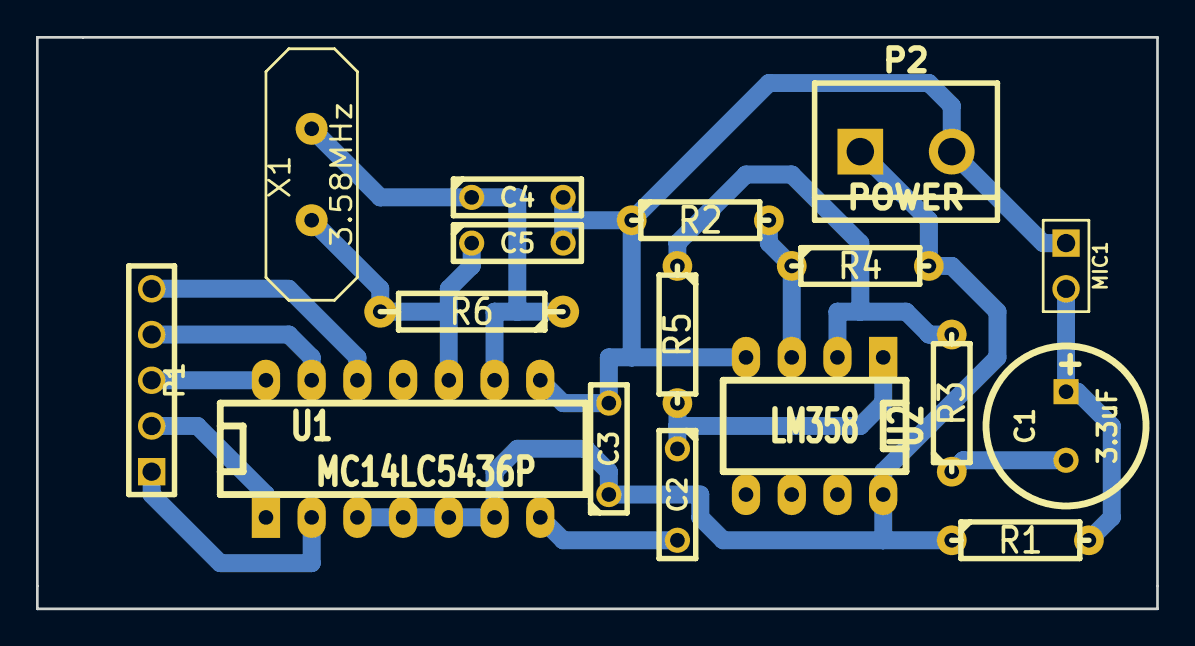
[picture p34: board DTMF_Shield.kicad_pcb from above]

Board: 2 copper layers, 62.2 x 31.7 mm, 17 parts (0 on the bottom side), 15 nets.

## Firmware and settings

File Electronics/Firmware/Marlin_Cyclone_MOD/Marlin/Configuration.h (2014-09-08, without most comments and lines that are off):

#define CONFIGURATION_H
#define STRING_VERSION_CONFIG_H __DATE__ " " __TIME__ // build date and time
#define STRING_CONFIG_H_AUTHOR "Carlosgs" //Who made the changes.
#define SERIAL_PORT 0
#define BAUDRATE 115200
#define MOTHERBOARD 62
#define POWER_SUPPLY 1
#define TEMP_SENSOR_0 0
#define TEMP_SENSOR_1 0
#define TEMP_SENSOR_2 0
#define TEMP_SENSOR_BED 0
#define TEMP_RESIDENCY_TIME 1	// (seconds)
#define TEMP_HYSTERESIS 3       // (degC) range of +/- temperatures considered "close" to the target one
#define TEMP_WINDOW     1       // (degC) Window around target to start the recidency timer x degC early.
#define HEATER_0_MINTEMP 5
#define HEATER_1_MINTEMP 5
#define HEATER_2_MINTEMP 5
#define BED_MINTEMP 5
#define HEATER_0_MAXTEMP 250
#define HEATER_1_MAXTEMP 250
#define HEATER_2_MAXTEMP 250
#define BED_MAXTEMP 120
#define PID_MAX 256 // limits current to nozzle; 256=full current
#define MAX_BED_POWER 256 // limits duty cycle to bed; 256=full current
#define PREVENT_DANGEROUS_EXTRUDE
#define PREVENT_LENGTHY_EXTRUDE
#define EXTRUDE_MINTEMP 170
#define EXTRUDE_MAXLENGTH (X_MAX_LENGTH+Y_MAX_LENGTH) //prevent extrusion of very large distances.
#define ENDSTOPPULLUPS // Comment this out (using // at the start of the line) to disable the endstop pullup resistors
  #define ENDSTOPPULLUP_XMAX
  #define ENDSTOPPULLUP_YMAX
  #define ENDSTOPPULLUP_ZMAX
  #define ENDSTOPPULLUP_XMIN
  #define ENDSTOPPULLUP_YMIN
  #define ENDSTOPPULLUP_ZMIN // CGS MOD: Our probe does work with a pullup (internal), just as the other endstops
const bool X_ENDSTOPS_INVERTING = false; // set to true to invert the logic of the endstops.
const bool Y_ENDSTOPS_INVERTING = false; // set to true to invert the logic of the endstops.
const bool Z_ENDSTOPS_INVERTING = false; // set to true to invert the logic of the endstops.
#define X_ENABLE_ON 0
#define Y_ENABLE_ON 0
#define Z_ENABLE_ON 0
#define E_ENABLE_ON 0 // For all extruders
#define DISABLE_X false
#define DISABLE_Y false
#define DISABLE_Z false
#define DISABLE_E false // For all extruders
#define INVERT_X_DIR false    // for Mendel set to false, for Orca set to true
#define INVERT_Y_DIR false    // for Mendel set to true, for Orca set to false
#define INVERT_Z_DIR false    // for Mendel set to false, for Orca set to true
#define INVERT_E0_DIR false   // for direct drive extruder v9 set to true, for geared extruder set to false
#define INVERT_E1_DIR false    // for direct drive extruder v9 set to true, for geared extruder set to false
#define INVERT_E2_DIR false   // for direct drive extruder v9 set to true, for geared extruder set to false
#define X_HOME_DIR -1
#define Y_HOME_DIR -1
#define Z_HOME_DIR 1 //CGS MOD: IMPORTANT: Our machine will have the Z endstop on top (Z axis will "home up")
#define min_software_endstops true //If true, axis won't move to coordinates less than HOME_POS.
#define max_software_endstops true  //If true, axis won't move to coordinates greater than the defined lengths below.
#define X_MAX_POS 135
#define X_MIN_POS 0
#define Y_MAX_POS 84
#define Y_MIN_POS 0
#define Z_MAX_POS 50
#define Z_MIN_POS -50
#define X_MAX_LENGTH (X_MAX_POS - X_MIN_POS)
#define Y_MAX_LENGTH (Y_MAX_POS - Y_MIN_POS)
#define Z_MAX_LENGTH (Z_MAX_POS - Z_MIN_POS)
#define MANUAL_X_HOME_POS 0
#define MANUAL_Y_HOME_POS 0
#define MANUAL_Z_HOME_POS 0
#define NUM_AXIS 4 // The axis order in all axis related arrays is X, Y, Z, E
#define HOMING_FEEDRATE {4*60, 4*60, 2*60, 0}  // set the homing speeds (mm/min)
#define Cyclone_XY_Gear_Ratio 21.0/15.0 // Number of tooth (motor/rod)
#define Cyclone_Z_Gear_Ratio 8.0/16.0 // Number of tooth (motor/rod)
#define DEFAULT_AXIS_STEPS_PER_UNIT   {3200.0/(Cyclone_XY_Gear_Ratio*1.25),3200.0/(Cyclone_XY_Gear_Ratio*1.25),3200.0/(Cyclone_Z_Gear_Ratio*1.25),800}  // steps per unit for Cyclone (original design)
#define DEFAULT_MAX_FEEDRATE          {500/60, 500/60, 250/60, 45}    // (mm/sec)
#define DEFAULT_MAX_ACCELERATION      {500/60,500/60,250/60,3000}    // X, Y, Z, E maximum start speed for accelerated moves. E default values are good for skeinforge 40+, for older versions raise them a lot.
#define DEFAULT_ACCELERATION          20     // X, Y, Z and E max acceleration in mm/s^2 for printing moves
#define DEFAULT_RETRACT_ACCELERATION  3000   // X, Y, Z and E max acceleration in mm/s^2 for r retracts
#define DEFAULT_XYJERK                5    // (mm/sec)
#define DEFAULT_ZJERK                 2.5   // (mm/sec)
#define DEFAULT_EJERK                 4.0    // (mm/sec)
#define PLA_PREHEAT_HOTEND_TEMP 180
#define PLA_PREHEAT_HPB_TEMP 70
#define PLA_PREHEAT_FAN_SPEED 255		// Insert Value between 0 and 255
#define ABS_PREHEAT_HOTEND_TEMP 240
#define ABS_PREHEAT_HPB_TEMP 100
#define ABS_PREHEAT_FAN_SPEED 255		// Insert Value between 0 and 255
#include "Configuration_adv.h"
#include "thermistortables.h"

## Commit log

2014-08-22 Add first FreeCAD converted pieces
    [Cyclone_X_carriage.fcstd, Cyclone_X_leftFrame.fcstd, Cyclone_X_rightFrame.fcstd]
2014-09-08 I think I have fixed the horror. Still learning git...
    [CNC_shieldBox.scad, CNC_shieldBox.stl, Configuration.h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]
2014-09-10 Updated some tolerances on FreeCAD LeftFrame and rightFrame & created a local copy of obiscad and MCAD
    [Cyclone_X_leftFrame.fcstd, Cyclone_X_leftFrame.stl, Cyclone_X_rightFrame.fcstd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]

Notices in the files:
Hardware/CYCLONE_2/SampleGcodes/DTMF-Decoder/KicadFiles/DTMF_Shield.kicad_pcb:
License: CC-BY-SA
